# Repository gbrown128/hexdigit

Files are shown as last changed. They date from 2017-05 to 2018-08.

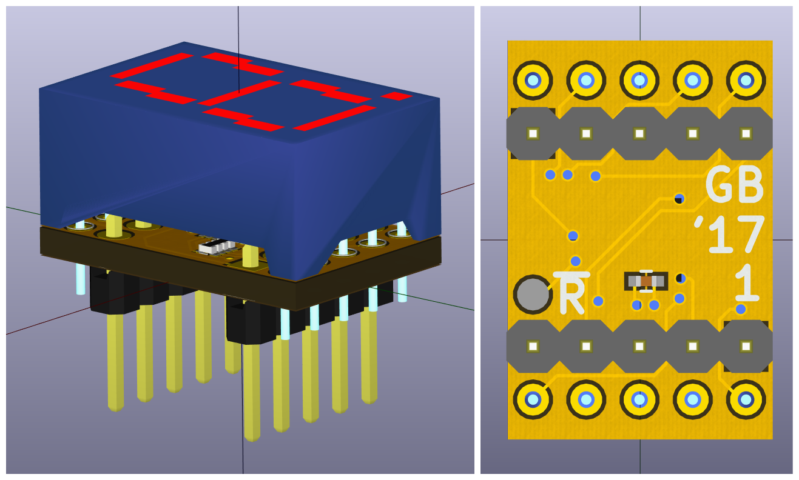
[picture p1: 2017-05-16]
hardware/3d-render.png

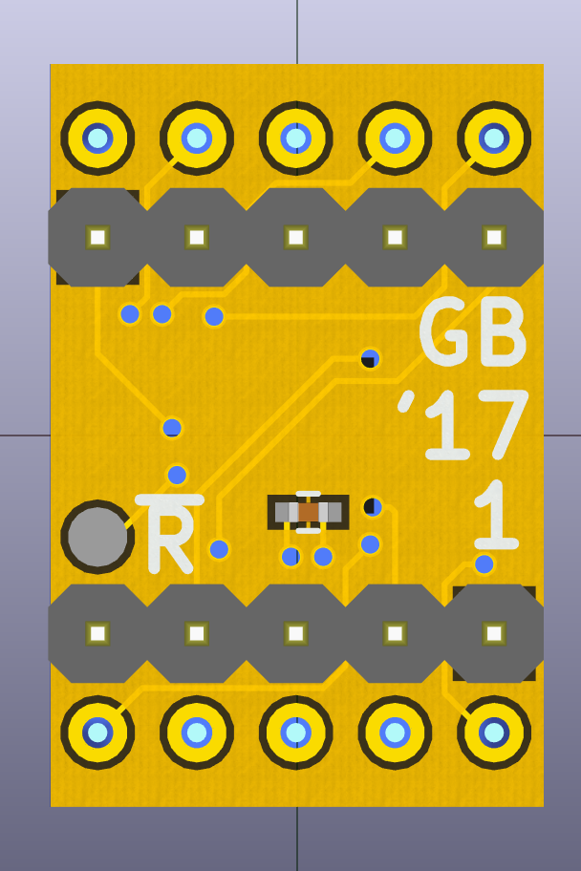
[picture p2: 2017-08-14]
hardware/underside.png

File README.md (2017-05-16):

# hexdigit
A 4-bit hex seven-segment display decoder.

Hex decoding by default, with blanking signal and an option to force decimal
display only.

Once the hardware is made, a range of additional features are planned, taking
advantage of the daisy chaining feature using UART.

# Hardware
Hardware KiCAD 3D render

The above render shows the basic goal of the product - to
fit entirley in the space of the seven-segment display, and
also have a DIP footprint for breadboarding.

The harware is based on an ATTiny1634, which has a whole 
host of capacity for future expansion.

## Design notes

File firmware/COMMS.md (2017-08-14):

In default 4-bit decode where no daisy chaining is required, there will be no UART communication.

Packet format:

Start of packet marker - 'P'
Mode - Mode ID
Position of the node sending the message first node sends it's position as zero.
Number of bytes to be sent of data.
The data itself. Typically there will be 4 bits added per node, though this will differ in analog mode.
Blank flag - if daisychanining is active, and member 0 is disabled, sleep the entire display.
End of packet marker - 'E'

Packets should be sent with a frequency of 10 Hz
9600 8n1 comms.

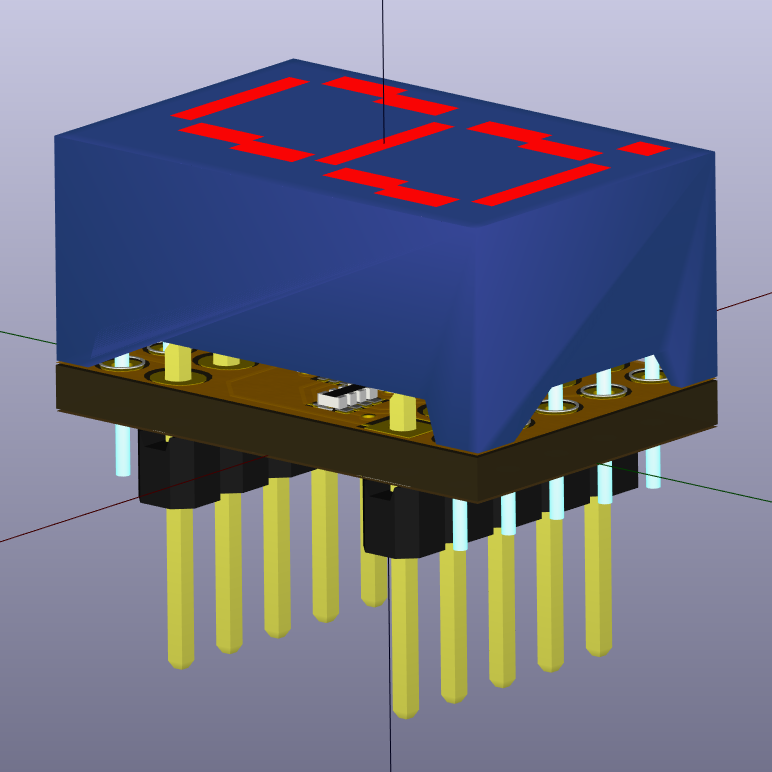
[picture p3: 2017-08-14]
hardware/side.png

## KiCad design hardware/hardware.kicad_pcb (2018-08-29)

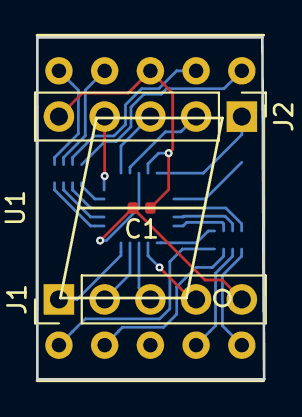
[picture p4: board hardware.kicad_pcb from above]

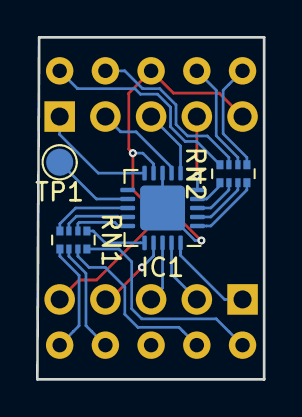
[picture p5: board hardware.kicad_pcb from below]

Board: 2 copper layers, 12.6 x 19.0 mm, 8 parts (4 on the bottom side), 27 nets.

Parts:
C1: 1u; C_0402_1005Metric
IC1: ATTINY1634-MU; QFN-20-1EP_4x4mm_P0.5mm_EP2.5x2.5mm
J1, J2: Conn_01x05_Male; PinHeader_1x05_P2.54mm_Vertical
RN1, RN2: 150; R_Array_Convex_4x0402
TP1: ~RESET; TestPoint_Pad_D1.5mm
U1: KCSA02-105; 7SegmentLED_LTS6760_LTS6780

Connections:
+5V: C1.1, IC1.9, J2.5, U1.8
/DA: RN2.7, U1.7
/DB: RN2.8, U1.6
/DC: RN1.6, U1.4
/DD: RN1.7, U1.2
/DDP: RN1.5, U1.5
/DE: RN1.8, U1.1
/DF: RN2.6, U1.9
/DG: RN2.5, U1.10
/~RESET: IC1.12, TP1.1
D0: IC1.5, J2.4
D1: IC1.6, J2.3
D2: IC1.7, J2.2
D3: IC1.10, J2.1
DC_I: IC1.18, J1.3
DC_O: IC1.19, J1.2
DEC: IC1.17, J1.4
EN: IC1.20, J1.1
GND: C1.2, IC1.8, IC1.21, J1.5
~DP: IC1.4, RN2.1
~SEG_A: IC1.14, RN1.3
~SEG_B: IC1.13, RN1.4
~SEG_C: IC1.3, RN2.2
~SEG_D: IC1.2, RN2.3
~SEG_E: IC1.1, RN2.4
~SEG_F: IC1.15, RN1.2
~SEG_G: IC1.16, RN1.1

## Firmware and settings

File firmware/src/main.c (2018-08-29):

/**
    \file main.c
    \author George Brown
    \date 2017-05-30T20:54:13+0100
    \brief Main code for the hexdigit.
*/

#include <avr/io.h>
#include <util/delay.h>

#include "hardware.h"
#include "display.h"
#include "font.h"

void raw_write(uint8_t pattern);
uint8_t read_input(void);

int main(void)
{
    uint8_t idx;

    // Set up the hardware.
    init_hw();

    // Turn on all digits as a hardware test.
    DP_ON();
    num_write(8);
    _delay_ms(250);
    DP_OFF();

    // Test loop.
    while(1){
        idx++;
        idx%=10;
        num_write(idx);
        _delay_ms(1000);
    }
    return 0;
}

uint8_t read_input(void)
{
    uint8_t value = 0;
    value = (PINB >> 1) & 0x07;
    value |= ((PINC << 2) & 0x08);
    return value;
}

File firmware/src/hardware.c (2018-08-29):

/**
    \file hardware.c
    \author George Brown
    \date 2017-12-18T22:54:41+0000
    \brief Hardware init functions.
*/

#include <avr/io.h>
#include "hardware.h"
#include "display.h"
#include "font.h"

void init_hw(void)
{
    init_gpio();
    init_uart();
    init_adc();
}

void init_gpio(void)
{
    // Input/Output directions.
    // 1 is output.
    // DP and C, D, E
    DDRA = 0b01111000;
    // UART Out. D0-2
    DDRB = 0b00000001;
    // A, B, G, and F
    DDRC = 0b00110101;

    // Pull up on inputs.
    PUEA = 0b10000110;
    PUEB = 0b00001110;
    PUEC = 0b00001010;

    // Ensure the display is off at startup.
    A_SEGMENTS(SPECIAL_BLANK_A);
    C_SEGMENTS(SPECIAL_BLANK_C);
    DP_OFF();
    return;
}

void init_uart(void)
{
    // Set up 9600 baud rate calculation.
    #include <util/setbaud.h>
    // Set baud rate.
    UBRR0H = UBRRH_VALUE;
    UBRR0L = UBRRL_VALUE;
    // Use doublespeed mode if needed.
    #if USE_2X
        UCSR0A |= _BV(U2X0);
    #else
        UCSR0A &= ~_BV(U2X0);
    #endif
    // Enable the transmit and receive hardware.
    UCSR0B |= _BV(RXEN0) | _BV(TXEN0);
    return;
}

void init_adc(void)
{
    // Power the ADC.
    PRR &= ~_BV(PRADC);
    // Input on PC1, Vcc Ref
    ADMUX = 0x0A;
    // Right adjust the result
    ADCSRB |= _BV(ADLAR);
    // Slow clock, and turn the ADC on, immediate reading taken.
    ADCSRA |= _BV(ADEN) | _BV(ADSC) | _BV(ADPS2) | _BV(ADPS1) | _BV(ADPS0);
    return;
}

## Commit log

2017-05-08 + Initial revision of schematic.
    [hexdigit.kicad_pcb, hexdigit.sch]
2017-05-08 * Changed schematic to make PCB tidier + Add initial rev of PCB
    [hexdigit.kicad_pcb, hexdigit.sch]
2017-05-16 * Tweaks
    [hexdigit.kicad_pcb, hexdigit.sch]
2017-05-16 * Redid the hardware to ensure DRC rules were correctly configured. * This version was sent out for check by the board house.
    [hardware.kicad_pcb, hardware.sch, hexdigit.kicad_pcb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]
2017-05-16 + BOM for first hardware run.
2017-05-16 + Add a 1uF decoupling capacitor to the power rails.
    [hardware.kicad_pcb, hardware.sch]
2017-05-17 + Add the gerbers sent out for the first prototype run.
    [hardware-B.Cu.gbr, hardware-B.Mask.gbr, hardware-B.SilkS.gbr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]
2017-05-30 + Full font set sweep as a sanity check. A mess because my micro has a broken PORTC!
    [main.c]
2017-05-30 + Now using the correct pin numbers - port D replaces port C on the atmega644p I'm using for programming because it's PORTC has some blown IO!
    [main.c]
2017-08-14 + Add Doxygen setup, commented the font file to play around with comment layout. * Some minor changes to the PCB, need to sanity check this commit (project has been a bit stagnant the past few months!
    [hardware.kicad_pcb]
2017-12-21 + Add an 'i' character as just segment C. Kinda works. + Add a string print mode. Not the best but it does work.
2018-08-29 + Add a hexidecimal display function. + Add initialisation for the ADC.
2018-08-29 * Redo layout to bring components to the bottom of the board. ** Note this has changed the device pinout somewhat! * Bring everything into kicad 5 + Add kicad ignores.
    [hardware.kicad_pcb, hardware.sch]
